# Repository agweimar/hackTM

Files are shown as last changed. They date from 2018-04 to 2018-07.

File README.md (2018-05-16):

# HackTM 2018 project #smucl

[Hardware overview](#hardware)

[Quickstart](#quickstart)

[Micropython](#mpython)

## Hardware overview 
The sensor board/shield holds three major components, namely:
* ESP32 breakout board with LoRa antenna and OLED display
* Flex Cable including I2C addressable Sensirion SHTC01 (rel. humidity and temperature) and SGP30 (multipixle gas sensor)
* Passive infrared sensor (PIR) a.k.a. motion sensor

A top view of the board is shown below:

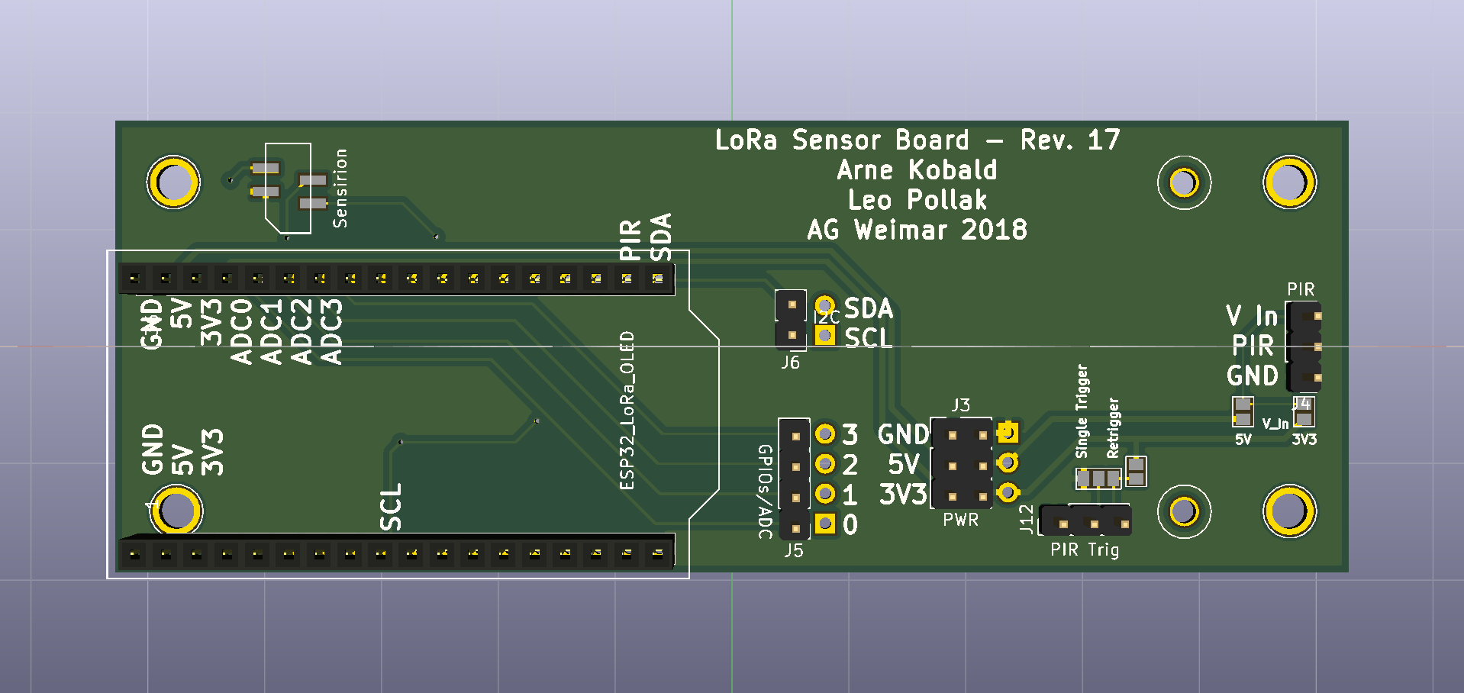
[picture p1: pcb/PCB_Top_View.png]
Top_View_Board


### ESP32 development board 

The ESP32 breakout board is put in the socket on the lower left of the board. The usb port is facing outwards, so the board can be powered from an external (USB) power supply.
On the bottom side of the ESP32 board a small LiPo battery can be connected. Charging this battery takes place via the USB port.  
_Caution_: When booting or running the board the LoRa antenna must be connected!  
[Schematic](https://download.bastelgarage.ch/Datasheet/WIFI_LoRa_32_868_Schema.png)
[Pinout](https://download.bastelgarage.ch/Datasheet/WIFI_LoRa_32_Pinout.pdf)

### Flex cable  
The flex cable is put in the FFC socket above the ESP32 board. It is to be mounted in such a fashion, that the sensors face upwards when the cable is bent to the right (parallel to the ESP32 board).  
The flex cable combines the Sensirion SHTC1 and SGP30. Both of the sensors are accessed via I2C. The former is a sensor for relative humidity and temperature, the latter a multipixle gas sensor.  
For both sensors a convenient micropython driver can be found in the micropython directory. 

#### SGP30  
The SGP30 can give raw readings corresponding to an Ethanol (EtOH) and Hydrogen (H2) signal. However, this chip can do more! If an In-Air-Qualitiy measurement has been initialized, the raw signals are used to calculate  
the a TVOC signal (total volatile organic compounds) and an CO2 equivalent (CO2eq). These values already underly a dynamic baseline correction performed on-chip. To ensure these corrections works properly, it is advised to perform an iaq measurement once per second.  
The power consumption of the chip can be drastically minimized by soft resetting it. This is done by an i2c general call. Caution is adviced, since other i2c devices might respont to this call as well. After each reset (hard or soft) the sensor starts in idle or sleep mode with lower power consumption. If a new iaq measurement is of intereset it needs to be initialized first,
otherwise the default values are CO2eq = 400 and TVOC = 0.  
For additional information see the below datasheet.  
[SGP30 Datasheet](https://www.sensirion.com/fileadmin/user_upload/customers/sensirion/Dokumente/0_Datasheets/Gas/Sensirion_Gas_Sensors_SGP30_Datasheet.pdf)  

#### SHTC1  
The SHTC1 sensor is a little simpler than the SGP30. It gives values for temperature and relative humidity. The sensor can be soft reseted, but doesn't have a sleep mode due to its already low power consumption.
[SHTC1 Datasheet](https://www.sensirion.com/fileadmin/user_upload/customers/sensirion/Dokumente/0_Datasheets/Humidity/Sensirion_Humidity_Sensors_SHTC1_Datasheet.pdf)  
Side note: The Sensirion sensors are powered with 1.8V. The electrical components taking care of voltage generation and conversion (for the I2C bus, including 10k pull-up resistors) are situated on the bottom side of the sensor board - see picture below:

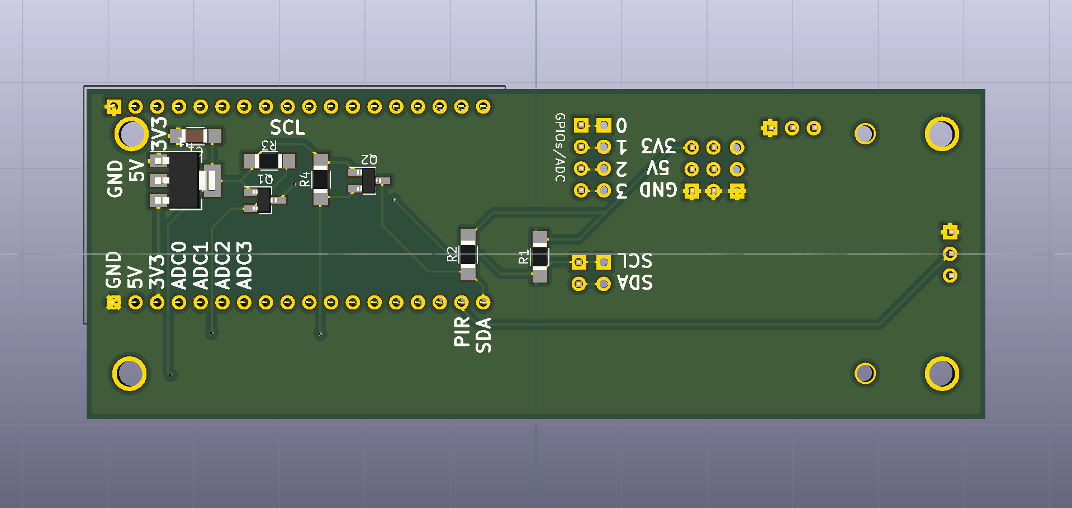
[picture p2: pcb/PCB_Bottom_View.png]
Top_View_Board


### PIR
The PIR sensor is placed on the right side of the sensor board. It produces a digital Signal (logic high) whenever a motion was detected. The sensor is internally powered by 3.3V. This voltage is generated on the PIR board by a voltage regulator.
The solder jumper labeled 'V_In' on the right side selects the input voltage - either 5V or 3.3V. Keep in mind that the 5V is only 'stable' when powered via USB.
Another (prefered and thus default) way to power the PIR Board is the second socket strip on the lower side. Originally those pins are designed to select the trigger mode (explained later). However, the outer two pins are connected to ground and 3.3V of the PIR sensor.
This enables the option to surpass the PIR's voltage regulator and save energy by directly supplying 3.3V.  
Via the solder jumpers labelled 'Single Trigger' and 'Retrigger' it can be selected if retriggering is possible. Retriggering is the possibility of increasing the duration of the digital output signal, when additional motion(s) are detected.
If 'Single Trigger' is selected the output signal will return to its default state () when a certain time has passed after detecting the first motion. Only now new motions cann trigger the sensor. The pulse length of the output signal can be selected with the left (when mounted upper) trimmable potentiometer.
The right (when mounted lower) potentiometer adjusts the sensitivity of the PIR sensor.  
[Example Datasheet](https://www.mpja.com/download/31227sc.pdf)
[Trigger Explanation](http://www.ladyada.net/media/sensors/BISS0001.pdf)

## Extras  
In addition to the previously mentioned features extra pins can be found on the sensor board. These are broken out pins (as well as solder eyelets) to conveniently expand the board.
They include the power pins (5V, 3.3V and GND - 5V may be limited to USB use) as well as the I2C pins SDA and SCL (3.3V level). Furthermore 4 GPIOs are broken out. Those can be used for a wide variety of scenarios.
All of them can be configured via software to be digital or analogue for different I/O devices. These pins could also be used as an SPI bus.

## Quickstart ESP32  

The ESP32 can be programmed using the Ardunio IDE, the Internet-of-Things Framework from Espressif or using [Micropython](https://micropython.org/). We chose Micropython, because it is very easy to start with and the code is very readable even for coders that are new to python.
Of course you can use your favourite IDE or even a simple text editor to code. However, below are a few suggestions of tools, that could make your life much easier.  

## Micropython  
In order to start with changing the sources for your needs, start looking in [micropython](micropython)

You can copy files to and from the board using different libaries:

### mpy utils  
[mpy-utils](https://github.com/nickzoic/mpy-utils) establishes a Filesystem in userspace connection to the board and allow you to change files directly on the board. (very handy)bla
_doesn't work on Windows_

### ampy
[ampy](https://github.com/adafruit/ampy) is used to interact with your esp32 board via serial connection.

### Atom with Pymakr Plugin
[Atom](https://atom.io/) can be used with the Pymakr Plugin (see [here](https://docs.pycom.io/chapter/pymakr/installation/atom.html) for help). Now you can use the powerful REPL (_Read-Evaluate-Print-Loop_),
which greatly helps while debubbing or prototyping. You can also run a pre-written script with just a click of a button (without uploading first).

### esptool.py
[esptool](https://github.com/espressif/esptool) is needed for flashing your esp32 with new firmware.

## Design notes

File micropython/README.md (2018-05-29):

# What's in this directory?

```
.
+-- upload_to_board.sh	- script for uploading all *.py files from currect directory to esp32
+-- LoBo-firmware	- working LoBo MicroPython firmware for our boards
|   +-- flash_board.sh	- bash script for flashing the firmware
|   +-- ...
+-- dep			- dependencies/drivers for our sensorboard which you probably won't need to change
|   +-- ...
+-- skeleton		- this is where you want to start developing your application
|   +-- ...
+-- archived
|   +-- continental	- continental test drive data
|   +-- drone		- drone flight data
|   +-- VEML		- working test code for VEML6040 
|   +-- sx1276_wei1234	- sx1276 driver examples written by "Wei1234c"
|   +-- ...
|   +-- old		- really old
|   |   +-- ...
```

## HOWTO: build LoBo firmware

[LoBo Instructions/dependencies](https://github.com/loboris/MicroPython_ESP32_psRAM_LoBo/wiki/build)

```bash
cd ~
git clone https://github.com/agweimar/hackTM.git
git clone https://github.com/loboris/MicroPython_ESP32_psRAM_LoBo.git
cd ~/MicroPython_ESP32_psRAM_LoBo/MicroPython_BUILD
```
remove example files from the internalfs image directory and the ssd1306 driver
```bash
rm -rf components/internalfs_image/image/*
rm components/micropython/esp32/modules/ssd1306.py
```
(optional) link the micropython files to the internalfs image
```bash
ln -s ~/hackTM/micropython/dep/* components/internalfs_image/image/
ln -s ~/hackTM/micropython/skeleton/* components/internalfs_image/image/
```
since the ssd1306 uses the framebuffer module you have to enable it first
```bash
./BUILD.sh menuconfig
```
Make sure your console is at least 19 lines by 80 columns, otherwise this will fail without any message.

go to:

MicroPython -> Modules -> [\*] Enable framebuffer 

Then build the firmware and the fs image

```bash
./BUILD.sh -j4 -v 
./BUILD.sh makefs
```

erase your flash to make sure everything is nice and clean

```bash
./BUILD.sh erase
```
then flash the firmware and fs image

```bash
./BUILD.sh flash flashfs
```

Note:

building/flashing the fs image is optional, you can also just use adafruit-ampy

to upload the mycropython files to your board

## TODO software

use config_sensorboard.py more extensively

## TODO doc

code documentation (doxygen?)

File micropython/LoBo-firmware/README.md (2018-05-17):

### howto flash board

```bash
esptool.py --chip esp32 --port /dev/ttyUSB0 --baud 921600 --before default_reset --after no_reset write_flash -z --flash_mode dio --flash_freq 40m --flash_size detect 0x1000 bootloader.bin 0xf000 phy_init_data.bin 0x10000 MicroPython.bin 0x8000 partitions_mpy.bin
```

```bash
esptool.py --chip esp32 --port /dev/ttyUSB0 --baud 921600 --before default_reset --after no_reset write_flash -z --flash_mode dio --flash_freq 40m --flash_size detect 0x150000 spiffs_image.img
```

- hard reset your board and you should be up and running

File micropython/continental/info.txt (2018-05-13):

SmUCL Testdrive protocoll 12th May 2018 / HackTM / Timisoara
(Thomas Heine / Univeristy of Tuebingen / LebensPhasenHaus)

reset of all modules: 15:11 (zero in SmUCL system time)

getting outside to mount modules: 15:33
Starting car: 15:55
Starting tour: 15:58
End Tour: 16:47

Sensor positions:
rear right : 240ac48df9dc
rear left: 240ac48e2ac0
indoor: 240ac48debe0
front bumper: 140ac48eb9d4

Data Format: space separated values
['ticks_us', 'SGP30_ETOH_RAW', 'RH', 'T', 'SGP30_TVOC', 'SGP30_H2_RAW', 'mac', 'payload_version', 'SGP30_CO2EQ']

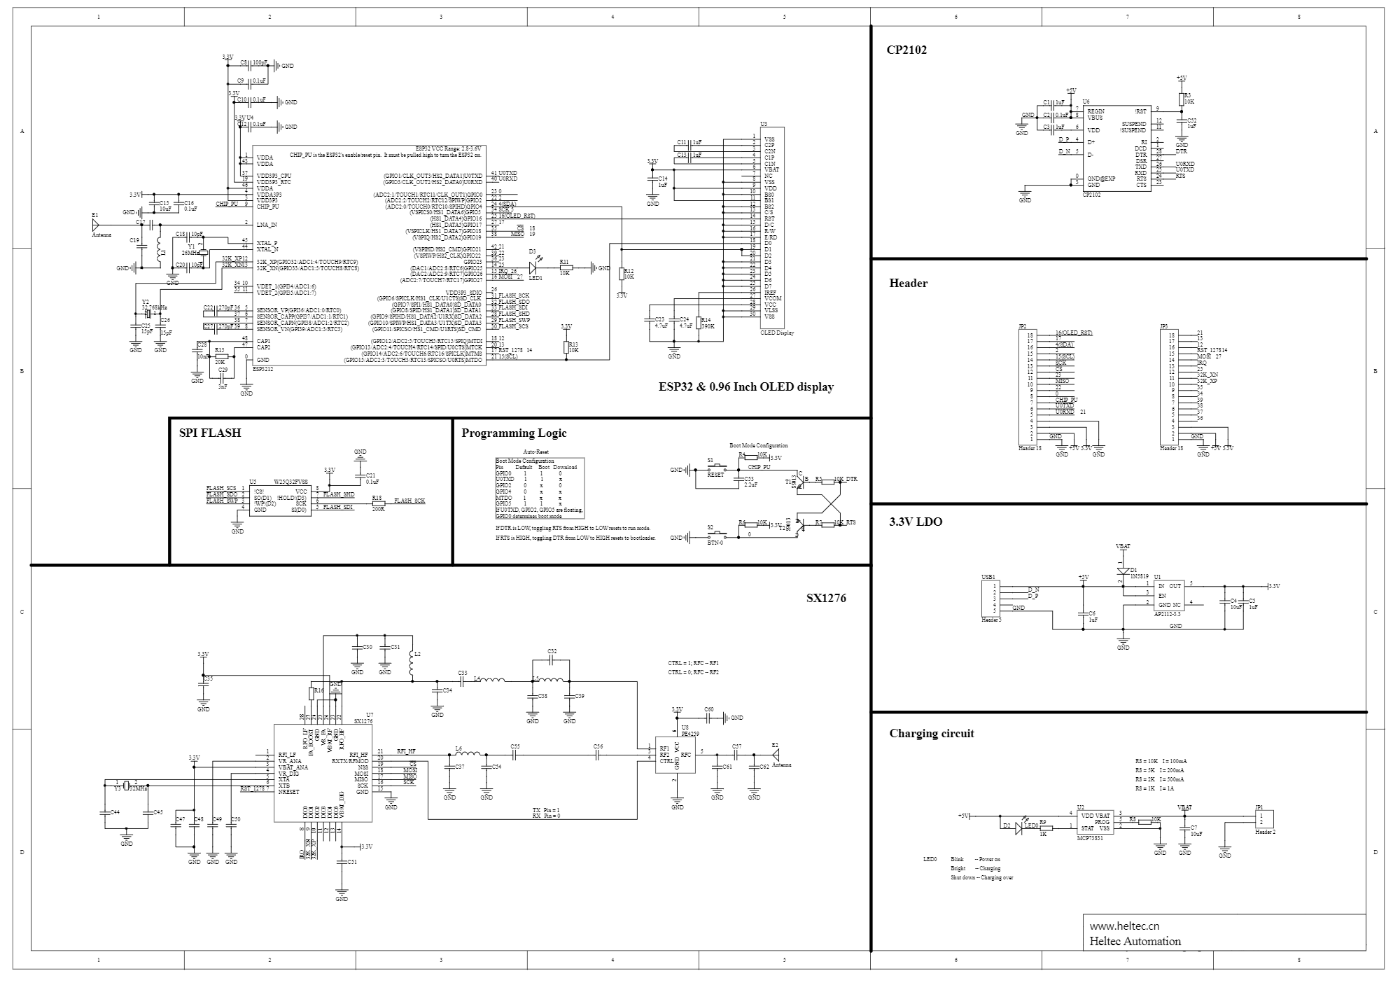
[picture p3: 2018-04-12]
doc/WIFI_LoRa_32_868_Schema.png

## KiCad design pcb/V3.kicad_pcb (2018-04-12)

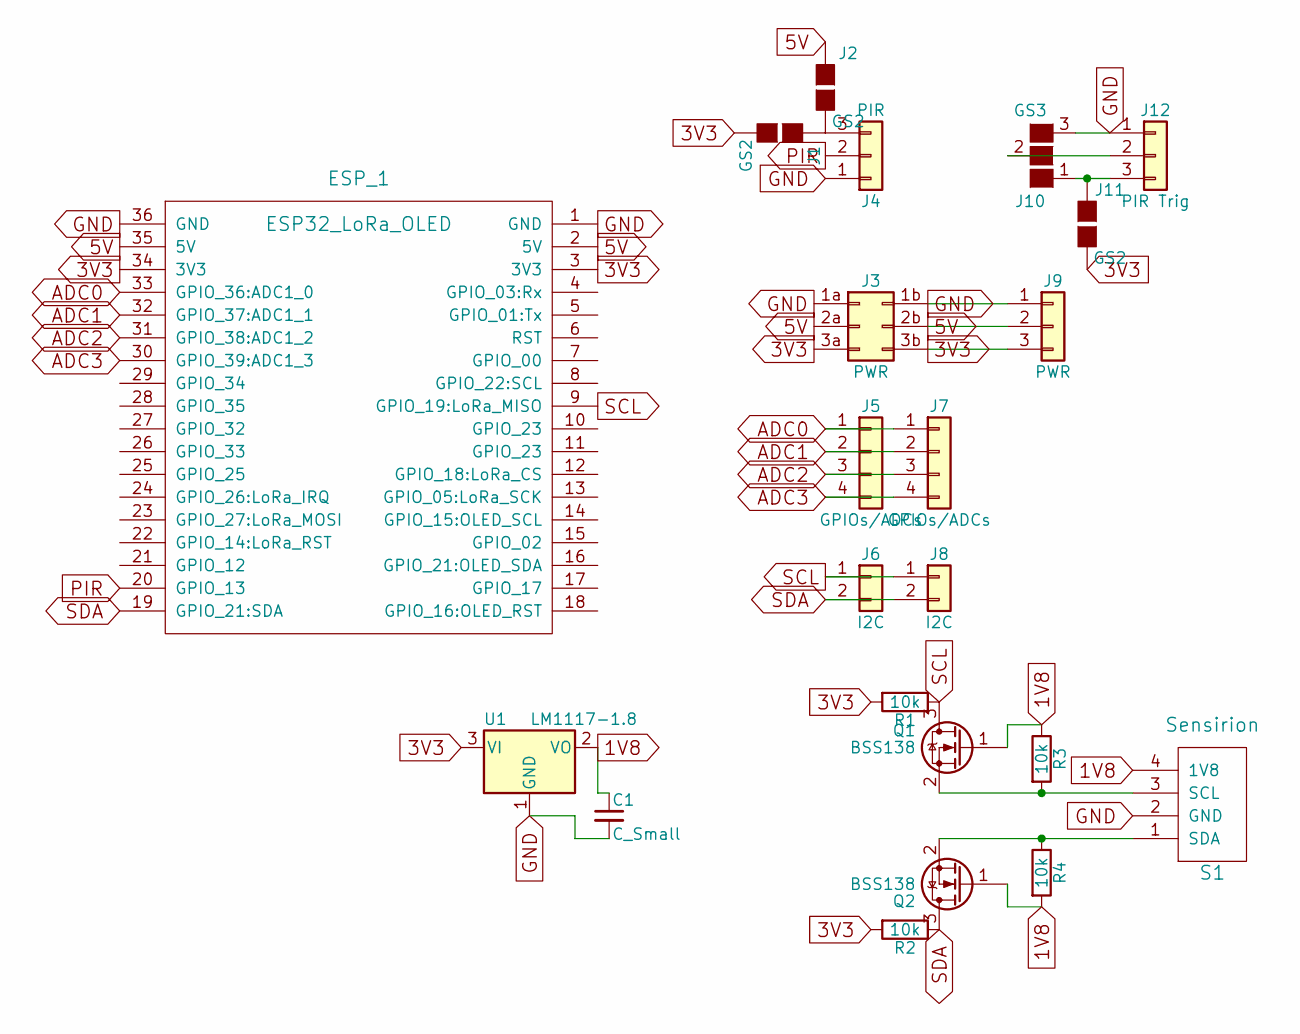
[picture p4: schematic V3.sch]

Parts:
C1: C_Small; C_1206_HandSoldering
ESP_1: ESP32_LoRa_OLED; ESP32_LoRa
J1, J2, J11: GS2
J3: PWR
J4: PIR; Pin_Header_Straight_1x03_Pitch2.54mm
J5, J7: GPIOs/ADCs; Pin_Header_Straight_1x04_Pitch2.54mm
J6, J8: I2C; Pin_Header_Straight_1x02_Pitch2.54mm
J9: PWR; Pin_Header_Straight_1x03_Pitch2.54mm
J10: GS3
J12: PIR Trig; Pin_Header_Straight_1x03_Pitch2.54mm
Q1, Q2: BSS138; SOT-23_Handsoldering
R1, R2, R3, R4: 10k; R_1206_HandSoldering
S1: Sensirion; FFC Amphenol
U1: LM1117-1.8; SOT-223-3_TabPin2

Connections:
1V8: C1.1, Q1.1 (G), Q2.1 (G), R3.1, R4.2, S1.4 (1V8), U1.2 (VO)
3V3: ESP_1.3 (3V3), ESP_1.34 (3V3), J1.2 (G2), J3.3a, J3.3b, J9.3, J11.2 (G2), R1.2, R2.2, U1.3 (VI)
5V: ESP_1.2 (5V), ESP_1.35 (5V), J2.1 (G1), J3.2a, J3.2b, J9.2
ADC0: ESP_1.33 (GPIO_36:ADC1_0), J5.1, J7.1
ADC1: ESP_1.32 (GPIO_37:ADC1_1), J5.2, J7.2
ADC2: ESP_1.31 (GPIO_38:ADC1_2), J5.3, J7.3
ADC3: ESP_1.30 (GPIO_39:ADC1_3), J5.4, J7.4
GND: C1.2, ESP_1.1 (GND), ESP_1.36 (GND), J3.1a, J3.1b, J4.1, J9.1, J10.3 (G3), J12.1, S1.2 (GND), U1.1 (GND)
unnamed: J1.1 (G1), J2.2 (G2), J4.3
unnamed: J10.1 (G1), J11.1 (G1), J12.3
unnamed: J10.2 (G2), J12.2
unnamed: Q1.2 (S), R3.2, S1.3 (SCL)
unnamed: Q2.2 (S), R4.1, S1.1 (SDA)
PIR: ESP_1.20 (GPIO_13), J4.2
SCL: ESP_1.9 (GPIO_19:LoRa_MISO), J6.1, J8.1, Q1.3 (D), R1.1
SDA: ESP_1.19 (GPIO_21:SDA), J6.2, J8.2, Q2.3 (D), R2.1

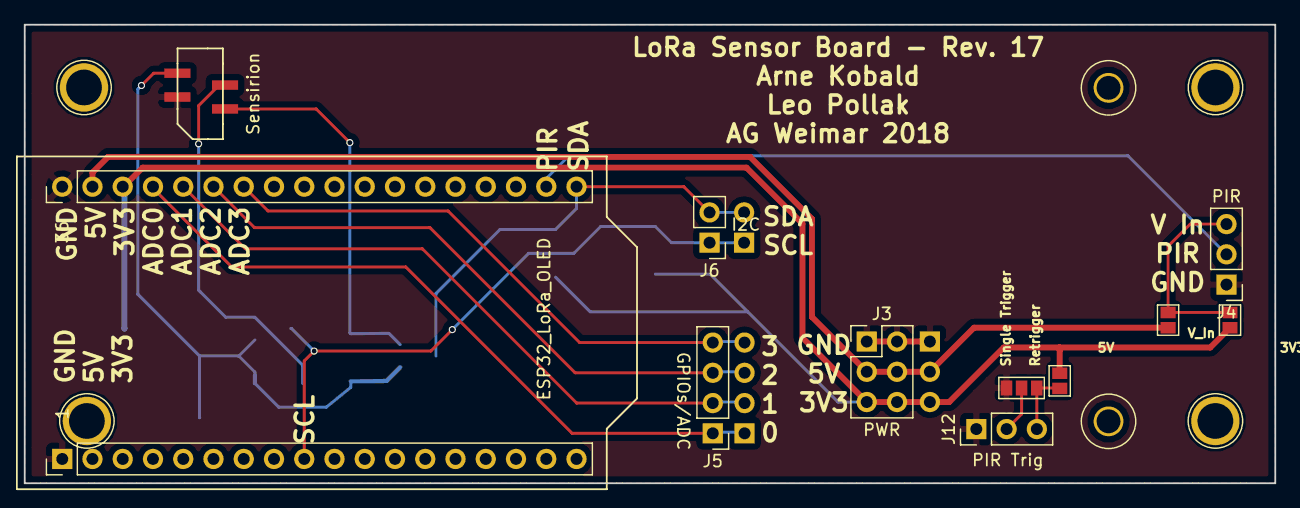
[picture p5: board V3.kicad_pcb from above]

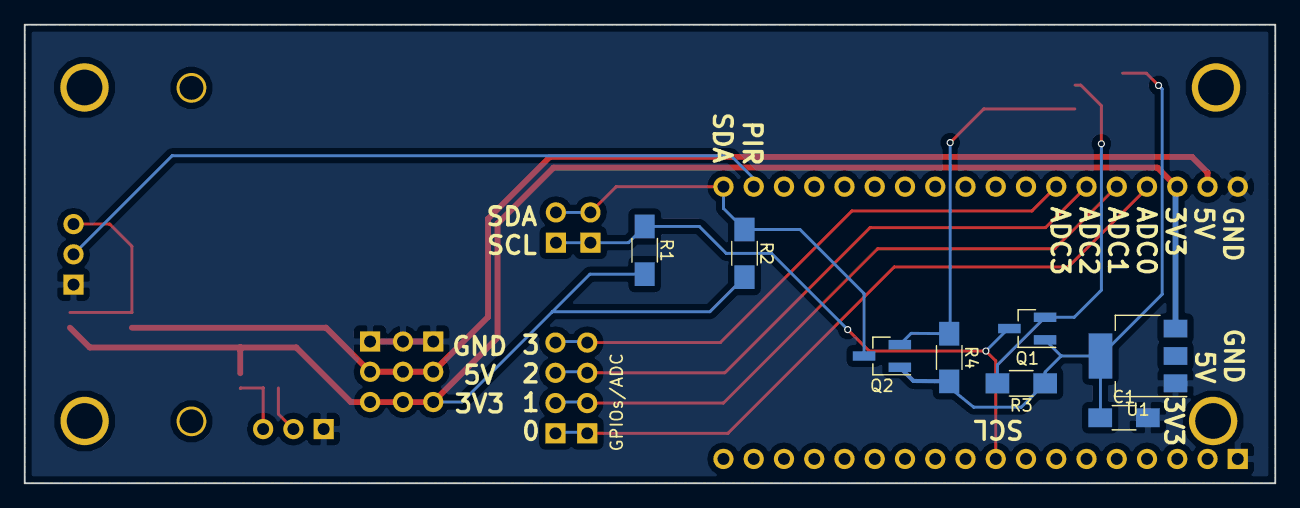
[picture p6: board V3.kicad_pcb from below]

Board: 2 copper layers, 105.0 x 38.5 mm, 22 parts (8 on the bottom side), 16 nets.

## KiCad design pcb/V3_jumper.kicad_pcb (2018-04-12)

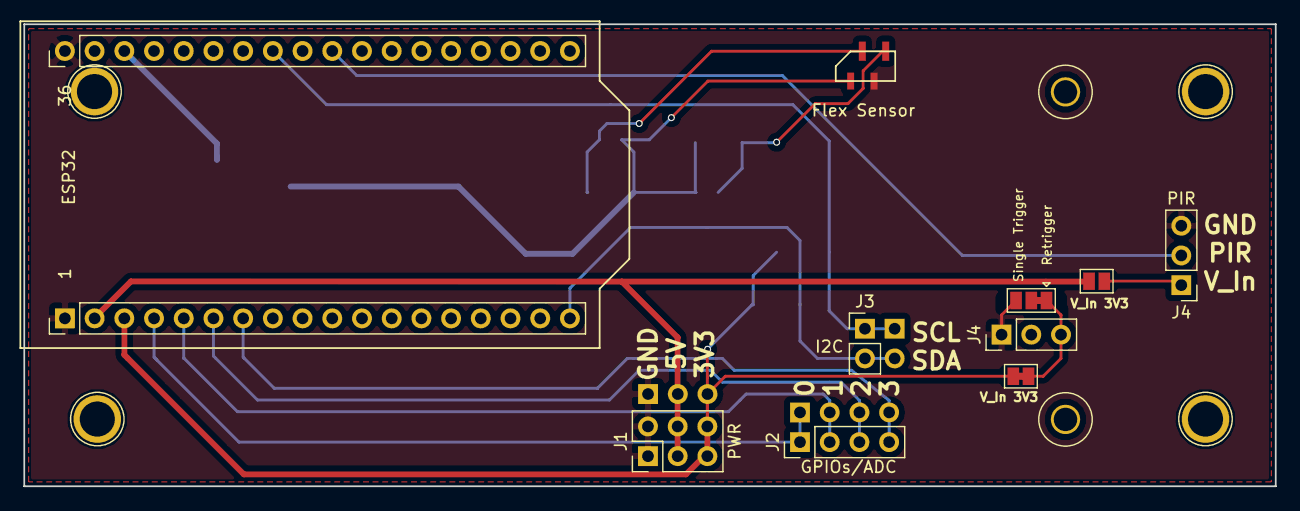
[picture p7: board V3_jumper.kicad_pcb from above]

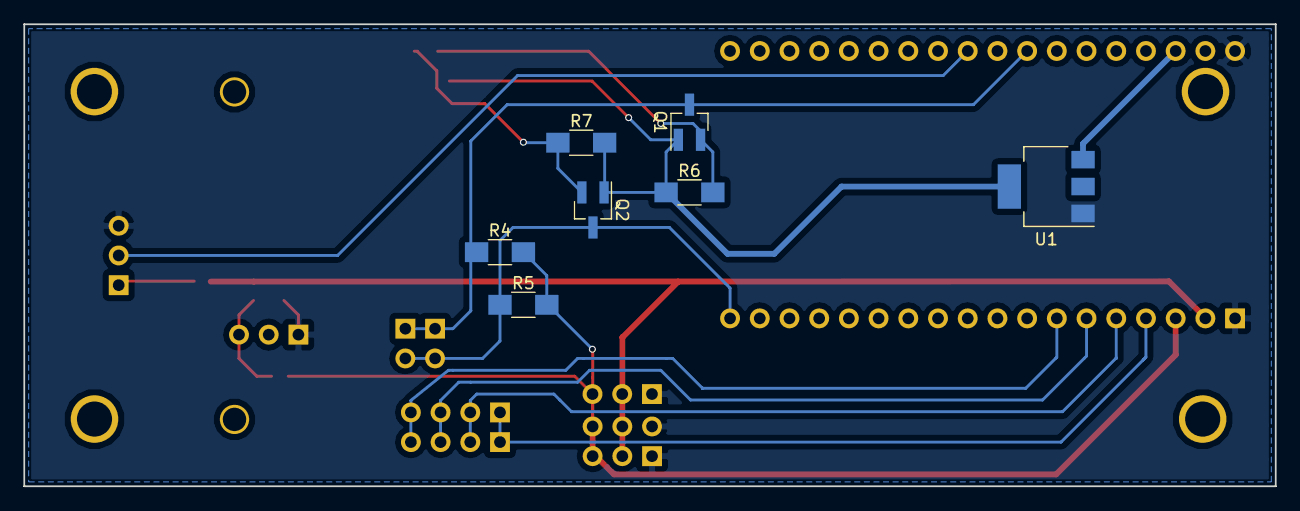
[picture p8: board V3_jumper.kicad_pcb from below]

Board: 2 copper layers, 107.0 x 39.5 mm, 14 parts (7 on the bottom side), 13 nets.

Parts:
ESP32: ESP32_LoRa_OLED; ESP32_LoRa
Flex Sensor: Sensirion; FFC Molex
J1: PWR
J2: Pin_Header_Straight_1x04_Pitch2.54mm
J3: I2C; Pin_Header_Straight_1x02_Pitch2.54mm
J4: Pin_Header_Straight_1x03_Pitch2.54mm
J4#2: PIR; Pin_Header_Straight_1x03_Pitch2.54mm
Q1, Q2: BSS138; SOT-23_Handsoldering
R4, R5, R6, R7: 10k; R_1206_HandSoldering
U1: LM1117-1.8; SOT-223-3_TabPin2

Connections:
1V8: Flex Sensor.1, Q1.1, Q2.1, R6.1, R7.2, U1.2
3V3: ESP32.3, ESP32.34, J1.3a, J1.3b, R4.2, R5.2, U1.3
5V: ESP32.2, ESP32.35, J1.2a, J1.2b
ADC0: ESP32.4, J2.1
ADC1: ESP32.5, J2.2
ADC2: ESP32.6, J2.3
ADC3: ESP32.7, J2.4
GND: ESP32.1, ESP32.36, Flex Sensor.3, J1.1a, J1.1b, J4.1, J4#2.3, U1.1
unnamed: Flex Sensor.2, Q1.2, R6.2
unnamed: Flex Sensor.4, Q2.2, R7.1
PIR: ESP32.27, J4#2.2
SCL: ESP32.29, J3.1, Q1.3, R4.1
SDA: ESP32.18, J3.2, Q2.3, R5.1

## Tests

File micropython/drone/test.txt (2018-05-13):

20316866 17796 26.7 33.3 0 13576 b4e62d859f75 99 400 592.6851109958995 2063.783489732082

25304518 17788 26.6 33.4 0 13572 b4e62d859f75 99 400 590.8106581301195 2063.783489732082

30304813 17786 26.5 33.4 0 13558 b4e62d859f75 99 400 588.9406122161094 2063.783489732082

35304526 17782 26.7 33.3 0 13555 b4e62d859f75 99 400 587.074957730603 2063.783489732082

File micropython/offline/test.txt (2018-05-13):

10556179 17471 33.2 32.3 0 13434 240ac48e2ac0 99 400

11198018 17464 32.9 32.3 0 13436 240ac48e2ac0 99 400

12198070 17472 32.6 32.3 0 13443 240ac48e2ac0 99 400

13198090 17479 32.3 32.3 0 13444 240ac48e2ac0 99 400

14198062 17474 32.1 32.4 0 13447 240ac48e2ac0 99 400

15198070 17476 32.0 32.4 0 13459 240ac48e2ac0 99 400

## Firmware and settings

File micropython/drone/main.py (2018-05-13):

# coding: utf-8

import gc
import machine
import utime
import sx127x
import config_sensorboard
from time import sleep

offline_flag = True

def pir_callback(p):
    global pir_flag
    #print('PIR triggered')
    pir_flag=True

def timer_callback(timer):
    global send_flag
    #print('timer isr')
    send_flag=True

adc_MQ_7 = machine.ADC(37)
adc_MQ_135 = machine.ADC(36)
adc_MQ_7.atten(adc_MQ_7.ATTN_6DB) #2.5 V
adc_MQ_135.atten(adc_MQ_135.ATTN_6DB) #2.5V
#adc_MQ_7.width(adc_MQ_7.WIDTH_10BIT)
#adc_MQ_135.width(adc_MQ_135.WIDTH_10BIT)

# PIR
pir_pin = machine.Pin(13, machine.Pin.IN, machine.Pin.PULL_DOWN)
#pir_pin.irq(trigger=machine.Pin.IRQ_FALLING, handler=pir_callback)
pir_pin.irq(trigger=machine.Pin.IRQ_RISING, handler=pir_callback)
pir_flag=False
pir_delay=1000*5

# timer for max send intervals
##### timer interrupt and soft reboot dont work well toegether this way --- -> OSError: 261
timer = machine.Timer(1)
timer.init(period=pir_delay, mode=machine.Timer.PERIODIC, callback=timer_callback)
send_flag=False

# Initialize controller
# add lora transceiver
controller = config_sensorboard.Controller()
lora = controller.add_transceiver(sx127x.SX127x(name = 'LoRa'))

gc.collect()

while 1:

    if send_flag==True:
        data = controller.collect_data()
        payload = controller.assemble_payload(data)
        if offline_flag:
            data_str = str(utime.ticks_us())
            for k in data.keys():
                if (type(data[k]) is float):
                    data_str += " " + str(round(data[k],1))
                else:
                    data_str += " " + str(data[k])

            u_7 = adc_MQ_7.read() * 2.5 / 2048
            R_MQ_7 = 1e3  * u_7 /(3.3 - u_7)
            u_135 = adc_MQ_135.read() * 2.5 / 2048
            R_MQ_135 = 1e3 * u_135/ (3.3- u_135)
            data_str += " " + str(round(R_MQ_7, 1))
            data_str += " " + str(round(R_MQ_135, 1))
            data_str += "\n\r"
            print(str(adc_MQ_7.read()) + " " +str(u_7) + " " + str(R_MQ_7))
            print(str(adc_MQ_135.read()) + " " + str(u_135) + " " + str(R_MQ_135))
            with open('log.txt','a') as f:
                f.write(data_str)

        controller.lora_send(lora, payload)
        lora.sleep()

        if pir_flag:
            controller.show_text("Motion detected", x = 0, y = 0, clear_first=True)
        else:
            controller.show_text("No Motion", x = 0, y = 0, clear_first = True)
        controller.show_text("MAC:"+config_sensorboard.UUID, x = 0, y = 8, clear_first=False)
        controller.show_text("T:" + str(round(data['T'],1)), x = 0, y = 16, clear_first=False)
        controller.show_text("RH:" + str(round(data['RH'],1)), x = 64, y = 16, clear_first=False)
        controller.show_text("Tv:"+str(data['SGP30_TVOC']), x = 0, y = 24, clear_first=False)
        controller.show_text("CO2eq:"+str(data['SGP30_CO2EQ']), x = 56, y = 24, clear_first=False)

        send_flag=False

        gc.collect()
        # see above
        #machine.enable_irq(irq_state)

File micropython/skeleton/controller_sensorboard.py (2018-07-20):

import controller_esp
import config_sensorboard
import display_basic

import machine
import zlib

import SGP30, SHTC1

class Controller(controller_esp.Controller, display_basic.Display):

    # Sensorboard config
    PAYLOAD_VERSION=2
    QOS=0

    PIN_NO_I2C_SCL = 22
    PIN_NO_I2C_SDA = 21
    FREQ_I2C = 10000


    #WIFI_IP        = '192.168.0.151'
    #WIFI_SUBNET    = '255.255.255.0'
    #WIFI_GATEWAY   = '192.168.0.1'
    #WIFI_DNS       = '84.200.69.80'
    #WIFI_SSID      = ""
    #WIFI_PASSWORD  =  ""

    # LoRa config
    PIN_ID_FOR_LORA_RESET = 14
    
    PIN_ID_FOR_LORA_SS = 18
    PIN_ID_SCK = 5
    PIN_ID_MOSI = 27
    PIN_ID_MISO = 19
    
    PIN_ID_FOR_LORA_DIO0 = 26
    PIN_ID_FOR_LORA_DIO1 = None 
    PIN_ID_FOR_LORA_DIO2 = None 
    PIN_ID_FOR_LORA_DIO3 = None
    PIN_ID_FOR_LORA_DIO4 = None
    PIN_ID_FOR_LORA_DIO5 = None 
    
    
    # OLED config
    PIN_ID_FOR_OLED_RESET = 16
    PIN_ID_SDA = 4
    PIN_ID_SCL = 15
    OLED_I2C_ADDR = 0x3C    
    OLED_I2C_FREQ = 400000
    OLED_WIDTH = 128
    OLED_HEIGHT = 32
    
    
    # ESP config
    ON_BOARD_LED_PIN_NO = 15
    ON_BOARD_LED_HIGH_IS_ON = False
    GPIO_PINS = (0, 1, 2, 3, 4, 5, 6, 7, 8, 9, 10, 11,
                 12, 13, 14, 15, 16, 17, 18, 19, 21, 22,
                 23, 25, 26, 27, 32, 34, 35, 36, 37, 38, 39) 
                 
    
    def __init__(self, 
                 pin_id_led = ON_BOARD_LED_PIN_NO, 
                 on_board_led_high_is_on = ON_BOARD_LED_HIGH_IS_ON,
                 pin_id_reset = PIN_ID_FOR_LORA_RESET,
                 blink_on_start = (2, 0.5, 0.5),
                 oled_width = OLED_WIDTH, oled_height = OLED_HEIGHT, 
                 scl_pin_id = PIN_ID_SCL, sda_pin_id = PIN_ID_SDA, 
                 freq = OLED_I2C_FREQ):
                 
        controller_esp.Controller.__init__(self,
                                           pin_id_led,
                                           on_board_led_high_is_on,
                                           pin_id_reset,
                                           blink_on_start)
                                           
        self.reset_pin(self.prepare_pin(self.PIN_ID_FOR_OLED_RESET))        
        display_basic.Display.__init__(self, 
                                             width = oled_width, height = oled_height, 
                                             scl_pin_id = scl_pin_id, sda_pin_id = sda_pin_id, 
                                             freq = freq)                                             
        # init i2c with sensirion sensors
        self.i2c = machine.I2C(1,scl = machine.Pin(self.PIN_NO_I2C_SCL), sda = machine.Pin(self.PIN_NO_I2C_SDA), freq = self.FREQ_I2C)

        self.sgp = SGP30.SGP30_Sensor(self.i2c)
        self.shtc = SHTC1.SHTC1_Sensor(self.i2c)
        self.sgp.iaq_init()
        #send sgp to sleep
        #self.sgp.soft_reset()
        
    def add_transceiver(self, 
                        transceiver, 
                        pin_id_ss = PIN_ID_FOR_LORA_SS,
                        pin_id_RxDone = PIN_ID_FOR_LORA_DIO0,
                        pin_id_RxTimeout = PIN_ID_FOR_LORA_DIO1,
                        pin_id_ValidHeader = PIN_ID_FOR_LORA_DIO2,
                        pin_id_CadDone = PIN_ID_FOR_LORA_DIO3,     
                        pin_id_CadDetected = PIN_ID_FOR_LORA_DIO4,
                        pin_id_PayloadCrcError = PIN_ID_FOR_LORA_DIO5):
         
        transceiver.show_text = self.show_text
        transceiver.show_packet = self.show_packet
        
        return super().add_transceiver(transceiver, 
                                       pin_id_ss,
                                       pin_id_RxDone,
                                       pin_id_RxTimeout,
                                       pin_id_ValidHeader,
                                       pin_id_CadDone,
                                       pin_id_CadDetected,
                                       pin_id_PayloadCrcError) 
                                       
                                       
    def show_packet(self, payload_string, rssi = None):
        self.clear()
        line_idx = 0
        if rssi:
            self.show_text('RSSI: {}'.format(rssi), x = 0, y = line_idx * 10, clear_first = False, show_now = False)
            line_idx += 1        
        self.show_text_wrap(payload_string, start_line = line_idx, clear_first = False)


    def collect_data(self):
        print("Reading sensors")
        #self.sgp.iaq_init()
        sgp_data = self.sgp.get_data()
        shtc_data = self.shtc.get_data()

        # send sgp to sleep
        #self.sgp.soft_reset()
        
        data = sgp_data
        data.update(shtc_data)
        print("sensirion raw sensor data: {0}".format(data))
    
        return data
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

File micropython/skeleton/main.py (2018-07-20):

# coding: utf-8
import gc
import machine
import utime
import sx127x
from config_sensorboard import *
import config_sensorboard
from time import sleep

def pir_callback(p):
    global pir_flag
    #print('PIR triggered')
    pir_flag=True

def timer_callback(timer):
    global update_flag
    #print('timer isr')
    update_flag=True

pir_flag = False
offline_flag = False
update_flag = False

# PIR
pir_pin = machine.Pin(13, machine.Pin.IN, machine.Pin.PULL_DOWN)
#pir_pin.irq(trigger=machine.Pin.IRQ_FALLING, handler=pir_callback)
pir_pin.irq(trigger=machine.Pin.IRQ_FALLING, handler=pir_callback)

# timer for max send intervals
##### timer interrupt and soft reboot dont work well toegether this way --- -> OSError: 261
timer_delay=1000*10
timer = machine.Timer(1)
timer.init(period=timer_delay, mode=machine.Timer.PERIODIC, callback=timer_callback)

# Initialize controller
# add lora transceiver
controller = config_sensorboard.Controller()

lora_parameters = {'frequency': 868.3E6, 'tx_power_level': 14, 'signal_bandwidth': 125E3,
                'spreading_factor': 9, 'coding_rate': 1, 'preamble_length': 12,
                'implicitHeader': False, 'sync_word': 0x12, 'enable_CRC': True}
lora_sx127x = sx127x.SX127x(name='LoRa', parameters=lora_parameters)

lora = controller.add_transceiver(lora_sx127x)

# sx127x.SX127x(name = 'LoRa'),
                    # parameters = {'frequency': 867.7E6, 'tx_power_level': 14, 'signal_bandwidth': 125E3,
                            #    'spreading_factor': 9, 'coding_rate': 1, 'preamble_length': 12,
                            #    'implicitHeader': False, 'sync_word': 0x12, 'enable_CRC': True}))
gc.collect()

while True:

    data = controller.collect_data()
    if update_flag:
        payload = controller.assemble_payload(data)


        if offline_flag:
            data_str = str(utime.ticks_us())

            for k in data.keys():
                data_str += " " + str(data[k])
            data_str += "\n\r"
            with open('log.txt','w') as f:
                f.write(data_str)

        controller.lora_send(lora, payload)
        lora.sleep()
        update_flag=False

    controller.show_text("MAC:" + config_sensorboard.UUID, x = 0, y = 8, clear_first=True)
    controller.show_text("T:" + str(round(data['T'],1)), x = 0, y = 16, clear_first=False)
    controller.show_text("RH:" + str(round(data['RH'],1)), x = 64, y = 16, clear_first=False)
    controller.show_text("Tv:"+str(data['SGP30_TVOC']), x = 0, y = 24, clear_first=False)
    controller.show_text("CO2eq:"+str(data['SGP30_CO2EQ']), x = 56, y = 24, clear_first=False)

    if pir_flag:
        controller.show_text("Motion detected", x = 0, y = 0, clear_first=False)
    else:
        controller.show_text("No Motion", x = 0, y = 0, clear_first=False)

    sleep(0.5)
    gc.collect()
    # see above
    #machine.enable_irq(irq_state)

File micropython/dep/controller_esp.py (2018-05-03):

from machine import Pin, SPI, reset
import config_sensorboard
import controller 
 

class Controller(controller.Controller):

    # LoRa config
    PIN_ID_FOR_LORA_RESET = 4 

    PIN_ID_FOR_LORA_SS = 15
    PIN_ID_SCK = 14 
    PIN_ID_MOSI = 13 
    PIN_ID_MISO = 12 

    PIN_ID_FOR_LORA_DIO0 = 5 
    PIN_ID_FOR_LORA_DIO1 = None 
    PIN_ID_FOR_LORA_DIO2 = None 
    PIN_ID_FOR_LORA_DIO3 = None
    PIN_ID_FOR_LORA_DIO4 = None
    PIN_ID_FOR_LORA_DIO5 = None  
    
    
    # ESP config
    ON_BOARD_LED_PIN_NO = 2
    ON_BOARD_LED_HIGH_IS_ON = True
    GPIO_PINS = (0, 1, 2, 3, 4, 5, 6, 7, 8, 9, 10, 11,
                 12, 13, 14, 15, 16, 17, 18, 19, 21, 22,
                 23, 25, 26, 27, 32, 34, 35, 36, 37, 38, 39) 

    
    def __init__(self,   
                 pin_id_led = ON_BOARD_LED_PIN_NO, 
                 on_board_led_high_is_on = ON_BOARD_LED_HIGH_IS_ON,
                 pin_id_reset = PIN_ID_FOR_LORA_RESET,
                 blink_on_start = (2, 0.5, 0.5)):
                
        super().__init__(pin_id_led,
                         on_board_led_high_is_on,
                         pin_id_reset,
                         blink_on_start)

        
    def prepare_pin(self, pin_id, in_out = Pin.OUT):
        if pin_id is not None:
            pin = Pin(pin_id, in_out)
            new_pin = Controller.Mock()
            new_pin.pin_id = pin_id
            new_pin.value = pin.value
            
            if in_out == Pin.OUT:
                new_pin.low = lambda : pin.value(0)
                new_pin.high = lambda : pin.value(1)        
            else:
                new_pin.irq = pin.irq 
                
            return new_pin

            
    def prepare_irq_pin(self, pin_id): 
        pin = self.prepare_pin(pin_id, Pin.IN) 
        if pin:
            pin.set_handler_for_irq_on_rising_edge = lambda handler: pin.irq(handler = handler, trigger = Pin.IRQ_RISING)
            pin.detach_irq = lambda : pin.irq(handler = None, trigger = 0)
            return pin
            
            
    def get_spi(self): 
        spi = None
        id = 1
        
        try:
            if config_sensorboard.SOFT_SPI: id = 1 #LoBo id = -1
            #spi = SPI(id, baudrate = 10000000, polarity = 0, phase = 0, bits = 8, firstbit = SPI.MSB,
            # LoBo
            spi = SPI(id, baudrate = 10000000, polarity = 0, phase = 0, bits = 8, firstbit = SPI.MSB,
                      sck = Pin(self.PIN_ID_SCK, Pin.OUT, Pin.PULL_DOWN),
                      mosi = Pin(self.PIN_ID_MOSI, Pin.OUT, Pin.PULL_UP),
                      miso = Pin(self.PIN_ID_MISO, Pin.IN, Pin.PULL_UP))
            spi.init()
                
        except Exception as e:
            print(e)
            if spi: 
                spi.deinit()
                spi = None
            reset()  # in case SPI is already in use, need to reset. 
        
        return spi
        
            
    def prepare_spi(self, spi): 
        if spi:
            new_spi = Controller.Mock()  

            def transfer(pin_ss, address, value = 0x00):        
                response = bytearray(1)

                pin_ss.low()
                 
                spi.write(bytes([address]))
                spi.write_readinto(bytes([value]), response)

                pin_ss.high()

                return response
                
            new_spi.transfer = transfer
            new_spi.close = spi.deinit            
            return new_spi
        
    def __exit__(self): 
        self.spi.close()
        

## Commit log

2018-04-12 added hackTM folder
    [V3-B.Cu.gbr, V3-B.Mask.gbr, V3-B.SilkS.gbr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]
2018-04-16 add Quickstart info for ESP32 / micropython
2018-04-19 sensor data via lora
    [partitions_mpy.csv]
2018-04-26 Update SHTC1.py soft reset
    [SHTC1.py]
2018-05-08 LoBo firmware rebuild with sgp30 driver update
2018-05-11 deepsleep, Button0
2018-05-13 changed defaults for higher tx power
